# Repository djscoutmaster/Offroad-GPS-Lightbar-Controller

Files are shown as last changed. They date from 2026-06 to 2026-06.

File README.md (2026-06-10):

# Smart Light Bar Controller

GPS controller designed for **Aurora Evolve adjustable beam pattern off-road light bars**.

## Assembled GPS controlller

<p align="center">
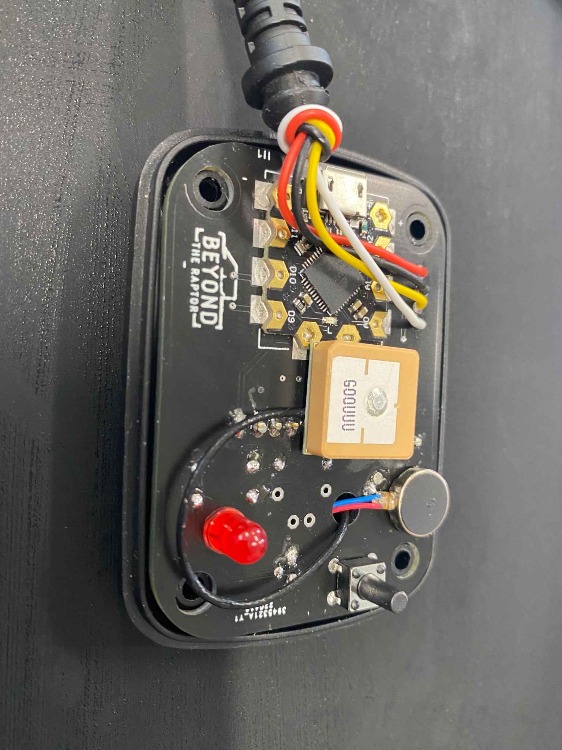
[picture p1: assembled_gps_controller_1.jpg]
Assembled GPS controller 1
  
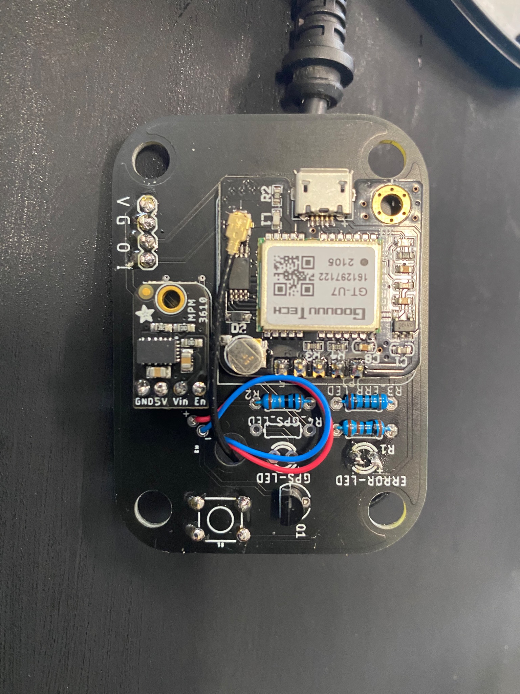
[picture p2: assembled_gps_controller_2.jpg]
Assembled GPS controller 2
  
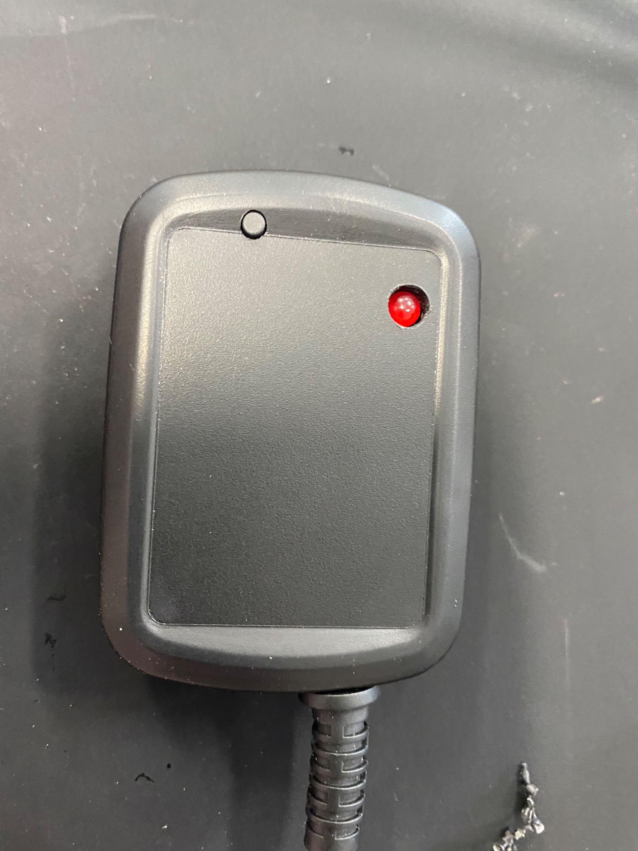
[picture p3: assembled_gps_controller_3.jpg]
Assembled GPS controller 3
  
</p>

## Aurora Evolve light bar

<p align="center">
  Aurora Evolve light bar
</p>

This project adds a smart GPS-based control layer to the Aurora Evolve system while still letting the user keep the original handheld controller behavior.

**Aurora Evolve product family:**  
https://lexbern.com/collections/aurora-evolve?srsltid=AfmBOorVTvPY1E8R5cCzJ8TLMzEkflyujZKsF8cvEtnp-r9cIhNQSOhc

**Final product demo:**  
https://www.youtube.com/watch?v=3yx3ybBsLAM

---

# Smart Light Bar Controller

Arduino-based smart controller for an off-road LED light bar. The controller sits between an existing manual lighting controller and the light bar, relays normal commands, and can automatically adjust the beam pattern based on GPS speed.

> **Project status:** Prototype / work in progress. GPS-driven light setting changes are implemented in the current sketch. Button behavior, accelerometer behavior, GPS 10 Hz updates, and non-blocking error handling are still being refined.

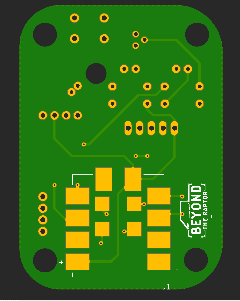
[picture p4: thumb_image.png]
Prototype board


## What it does

The Smart Light Bar Controller, or **SLC**, listens to the existing lighting controller's 5 V digital signal and retransmits compatible commands to the light bar. When GPS mode is active, the SLC uses vehicle speed to select one of six beam settings:

| Speed range example | Light setting | Beam behavior |
|---:|---:|---|
| 0-9 mph | 1 | Widest pattern |
| 10-19 mph | 2 | Wide |
| 20-29 mph | 3 | Medium-wide |
| 30-39 mph | 4 | Medium-narrow |
| 40-49 mph | 5 | Narrow |
| 50+ mph | 6 | Narrowest / spot pattern |

The default high-speed threshold is **50 mph**. The intent is for the user to be able to set that threshold from the current GPS speed using the onboard button.

## Core features

- Reads GPS speed using TinyGPS++.
- Maps speed into six light-bar settings.
- Sends the light-bar setting command over a 5 V digital output.
- Avoids resending a light setting when the setting has not changed.
- Provides six indicator LEDs for the active speed/light setting.
- Provides a status LED and an error LED.
- Includes early support for an ADXL345 accelerometer and activity/inactivity detection.
- Includes early support for a momentary button and piezo buzzer.
- Includes PCB design files, Gerbers, drill files, and assembly output.

## Hardware

See [`PARTS.md`](PARTS.md) for a cleaner parts list and recommended additions.

### Controller and modules

- Arduino-compatible controller. The requirements document calls for an **Arduino Mega 2560**. The existing parts list also references a compact **DFRobot Beetle**, so confirm which board you want as the official target before publishing.
- GPS module compatible with **NEO-6M** / **GT-U7** style serial GPS modules.
- ADXL345-compatible accelerometer.
- Piezo buzzer, such as TBM12A05-compatible.
- Momentary push button.
- Six light-setting indicator LEDs.
- One accelerometer/status LED.
- One error LED.
- 5 V digital signal interface to the existing lighting controller and light bar.

### Current Arduino pin map

| Function | Pin | Notes |
|---|---:|---|
| Button input | 2 | Uses `ezButton` debounce handling. |
| Light command transmit | 3 | Sends light-bar command timing pulses. |
| Buzzer | 4 | Uses `tone()`. Current beep functions use blocking delays. |
| GPS RX/TX constants | 19 / 18 | Defined in code, but the current sketch uses `Serial2`. Verify the final wiring. |
| Light setting LED 1 | 41 | Setting 1 / wide. |
| Light setting LED 2 | 42 | Setting 2. |
| Light setting LED 3 | 43 | Setting 3. |
| Light setting LED 4 | 44 | Setting 4. |
| Light setting LED 5 | 45 | Setting 5. |
| Light setting LED 6 | 46 | Setting 6 / spot. |
| Additional output | 47 | Configured as output; document final purpose. |
| Blue status LED | 48 | Used for GPS speed update/status in current sketch. Intended for accelerometer state. |
| Error LED | 49 | Used for GPS/error status. |

## Software dependencies

Install these libraries in the Arduino IDE Library Manager or through your preferred Arduino workflow:

- `TinyGPS++`
- `SparkFun ADXL345 Arduino Library`
- `ezButton`

## Getting started

1. Clone the repository.
2. Open `Smart_Light_Bar_Controller.ino` in the Arduino IDE.
3. Install the required libraries listed above.
4. Select the correct board. The current requirements target **Arduino Mega 2560**.
5. Confirm the GPS serial port and baud rate:
   - Default baud rate: `9600`
   - Current sketch uses `Serial2.begin(GPSBaud)`
6. Confirm all pins match your wiring.
7. Upload the sketch.
8. Open Serial Monitor at `9600` baud for debug output.

## Configuration points

The main tuning values are currently near the top of `Smart_Light_Bar_Controller.ino`:

```cpp
static const uint32_t GPSBaud = 9600;
int spotSpeed = 50;           // MPH for full spot setting
int lightSettingsSpeeds[5];   // Calculated speed thresholds
const int buzzerPin = 4;
static const int lightTXPin = 3;
```

The threshold table is recalculated by dividing `spotSpeed` into five threshold breakpoints. For example, `spotSpeed = 50` creates thresholds at 10, 20, 30, 40, and 50 mph.

## Current behavior

### GPS speed mode

When GPS speed is valid, the controller:

1. Reads the current GPS speed in mph.
2. Clears the error LED.
3. Selects the matching light setting from 1-6.
4. Turns on the matching setting LED.
5. Sends the timing pulse sequence for the selected light setting.

### Light command output

`sendLightSetting(int lightIndex)` sends the command timing pattern on `lightTXPin`. It uses the same leading pulse structure for all settings and then repeats short pulses based on the selected setting.

The function skips transmission when the requested setting is already active.

### Error behavior

The current sketch turns the error LED on while waiting for a valid GPS speed. It also halts in a `while(true)` loop if no GPS characters are processed after five seconds.

This should be changed before field use. See [`TODO.md`](TODO.md) for the recommended non-blocking error handling work.

## Planned improvements

The highest-value improvements before calling this GitHub-ready are:

- Configure the GPS module for **10 Hz updates**, or add interpolation between GPS updates.
- Replace all blocking `delay()` and `while(true)` behavior with non-blocking `millis()` state machines.
- Implement the 3-second and 10-second button hold behavior.
- Store the user-selected high-speed threshold in EEPROM.
- Finish ADXL345 interrupt handling and make inactivity/activity callbacks easy to customize.
- Flash the red error LED at 500 ms intervals when GPS speed is unavailable.
- Turn off speed-setting LEDs when not in GPS mode.
- Add bench-test instructions and a simple wiring diagram.

## Repository structure

```text
Smart_Light_Bar_Controller/
├── Smart_Light_Bar_Controller.ino      # Main Arduino sketch
├── README.md                           # Project overview and setup
├── PARTS.md                            # Cleaned-up BOM / parts list
├── TODO.md                             # Implementation checklist
├── GITHUB_PROJECT_RECOMMENDATIONS.md   # Publishing recommendations
├── thumb_image.png                     # Prototype image
└── PCB DESIGN/
    ├── *.pcbdoc / *.dxf                # PCB design exports
    └── Gerber out/
        ├── GerberFiles/                # PCB manufacturing files
        ├── DrillFiles/                 # Drill files
        └── Assembly/                   # Assembly output
```

## Safety notes

This is a vehicle electrical project. Use proper fusing, strain relief, wire gauge, waterproofing, and electrical protection before installing it in a vehicle. Do not rely on breadboard wiring for vehicle use. Validate that the controller cannot accidentally turn lights on, change modes unexpectedly, or interfere with required lighting.

## License

No license has been selected yet. Before publishing publicly, add a license file such as MIT, Apache-2.0, GPL-3.0, or a private/proprietary notice depending on how you want others to use the project.

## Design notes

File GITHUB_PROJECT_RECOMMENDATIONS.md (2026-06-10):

# GitHub Project Recommendations

These are the main improvements I would make before sharing this publicly or sending it to other builders.

## 1. Make the target hardware unambiguous

Right now the documentation points in two directions:

- The project requirements call for an Arduino Mega 2560.
- The original parts list includes a DFRobot Beetle.
- The current sketch uses pins 41-49, which only makes sense on a larger board like the Mega.

**Recommendation:** publish the first GitHub version as an **Arduino Mega 2560 prototype**. Then add a future milestone for a compact PCB/controller version.

## 2. Add one simple wiring diagram

The repo will be much easier to understand with a diagram showing:

- Existing lighting controller signal input.
- Smart Light Bar Controller board.
- Light-bar signal output.
- Shared ground.
- 12 V vehicle power into the buck converter.
- 5 V controller power.
- GPS, accelerometer, button, buzzer, and LEDs.

Even a clean hand-drawn diagram exported as PNG would help a lot.

## 3. Add a short demo video or GIF

A GitHub README for a hardware project becomes much stronger when the first screen shows it working. The best demo would show:

1. GPS speed changing.
2. Active LED setting changing from 1-6.
3. The light command being sent only when the setting changes.
4. Error LED behavior when GPS is unavailable.

## 4. Convert the code to a non-blocking state-machine style

The current sketch still uses blocking patterns like `delay()` and `while(true)`. That is risky because the controller needs to keep reading GPS, button state, accelerometer interrupts, and signal timing without freezing.

Recommended code structure:

```text
loop()
├── readGps()
├── updateGpsMode()
├── updateButtonState()
├── updateAccelerometerState()
├── updateErrorState()
├── updateIndicatorLeds()
└── transmitLightCommandIfNeeded()
```

## 5. Add a pin map diagram and constants section

The README now includes a pin table, but the code would be easier to maintain if every pin lived in one clearly labeled section:

```cpp
const uint8_t PIN_BUTTON = 2;
const uint8_t PIN_LIGHT_TX = 3;
const uint8_t PIN_BUZZER = 4;
const uint8_t PIN_LED_SETTING_1 = 41;
...
```

## 6. Add release levels

Use GitHub releases or tags like:

- `v0.1-prototype-gps-speed-control`
- `v0.2-non-blocking-button-buzzer`
- `v0.3-accelerometer-status`
- `v1.0-vehicle-tested`

This helps people understand what is tested versus experimental.

## 7. Add safety and install disclaimers

Because this interfaces with vehicle lighting and 12 V power, make it clear that builders need proper fusing, wire gauge, waterproofing, strain relief, and safe test procedures.

## 8. Decide how open you want it to be

Before publishing, choose a license:

- **MIT:** easiest for people to reuse.
- **Apache-2.0:** permissive, with stronger patent language.
- **GPL-3.0:** requires derivatives to stay open source.
- **No license / all rights reserved:** public viewing only; not really open source.

## 9. Clean up repo naming over time

For a future cleanup, consider this structure:

```text
Smart_Light_Bar_Controller/
├── firmware/
│   └── Smart_Light_Bar_Controller/
│       └── Smart_Light_Bar_Controller.ino
├── hardware/
│   ├── pcb/
│   └── gerbers/
├── docs/
│   ├── wiring.md
│   └── signal-timings.md
├── images/
├── README.md
├── PARTS.md
└── TODO.md
```

I did not restructure the repo automatically because that can break Arduino IDE expectations unless the sketch folder is moved carefully.

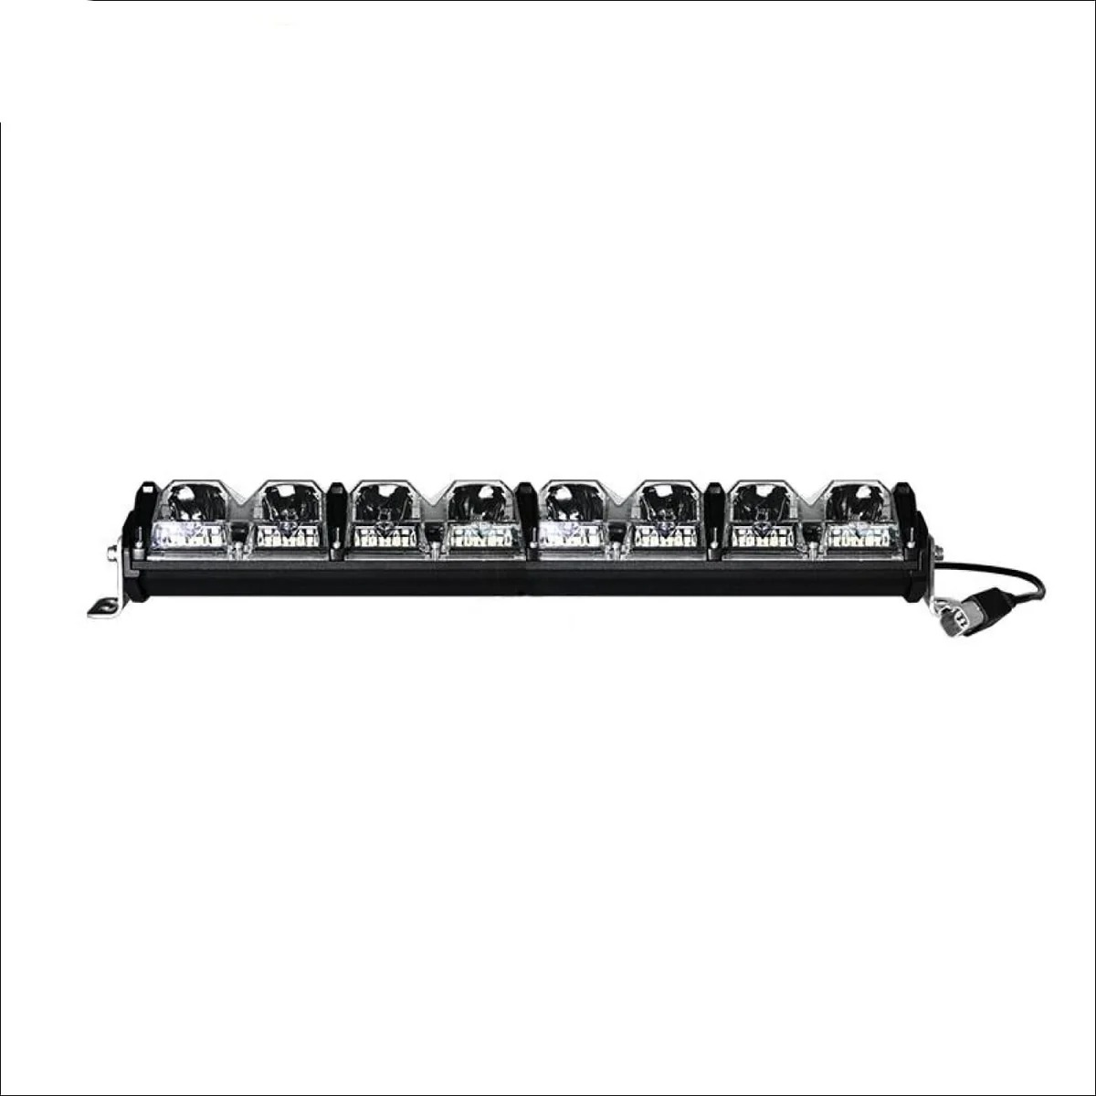
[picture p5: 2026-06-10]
docs/assets/aurora_evolve_light_bar.jpg

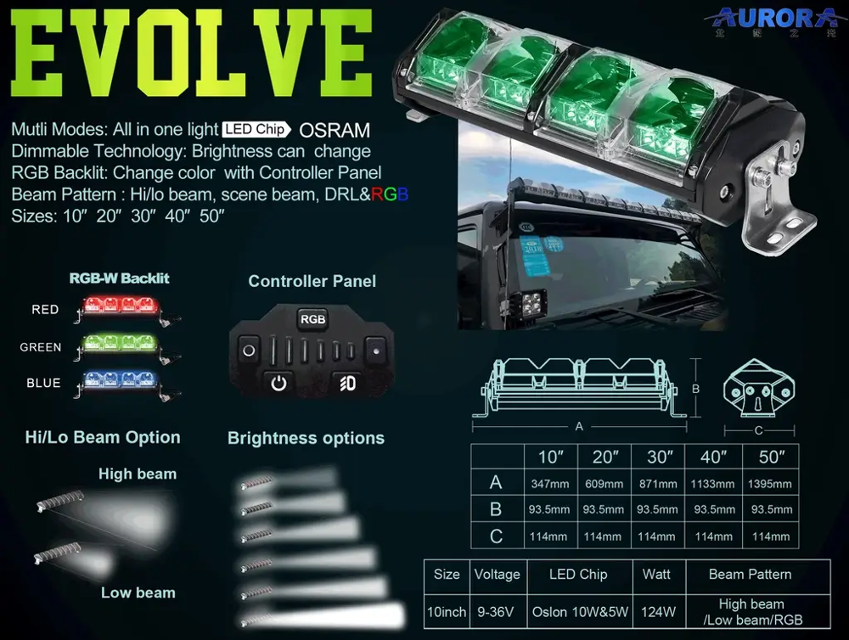
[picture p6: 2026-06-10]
aurora_evolve_light_bar_reference.png

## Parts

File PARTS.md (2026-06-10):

# Parts List / Bill of Materials

This list combines the original prototype parts list with the requirements from the project document. Items marked **Verify** need a final decision before ordering or publishing the repo.

## Required controller parts

| Qty | Part / module | Example / compatible part | Purpose | Status | Notes |
|---:|---|---|---|---|---|
| 1 | Main microcontroller | Arduino Mega 2560 | Runs the Smart Light Bar Controller sketch | **Required / verify** | The requirements target a Mega 2560. The original compact parts list references a DFRobot Beetle, so pick one official target. Current pin usage strongly favors the Mega because pins 41-49 are used. |
| 1 | GPS module | NEO-6M-compatible or GT-U7 GPS module | Reads vehicle speed | Required | Confirm serial voltage level, antenna placement, and whether the module supports 10 Hz updates. |
| 1 | Accelerometer | ADXL345-compatible module | Detects activity/inactivity state | Required / partially implemented | Use I2C or SPI consistently and document the interrupt pin. |
| 1 | Momentary push button | 6 mm x 6 mm through-hole push button | User input for speed calibration | Required | Current sketch uses pin 2 with debounce. |
| 1 | Piezo buzzer | TBM12A05-compatible | Audible feedback for button actions and status | Required | Current sketch uses pin 4. |
| 6 | Indicator LEDs | 3 mm or 5 mm LEDs | Shows active light setting 1-6 | Required | Add current-limiting resistors. |
| 1 | Blue status LED | 3 mm or 5 mm blue LED | Accelerometer/status indication | Required | Intended for inactivity/activity state. Current code also uses it during GPS update checks. |
| 1 | Red error LED | 3 mm or 5 mm red LED | GPS and signal error indication | Required | Should flash non-blocking for error states. |
| 8+ | LED resistors | 220-330 Ω typical | Limits LED current | Required | Size based on LED forward voltage and desired brightness. |
| 1 | 5 V buck regulator | Adafruit MPM3610 Buck Converter or automotive-rated 12 V-to-5 V converter | Powers controller from vehicle 12 V | Required / verify | For vehicle use, prefer an automotive-rated regulator with transient protection. |
| 1 | Enclosure | New Age Medium Utility S-352510 | Protects electronics | Prototype part | Original parts list references this enclosure. Confirm fit with final PCB and connectors. |

## Signal interface and vehicle-install parts

| Qty | Part / module | Purpose | Recommendation |
|---:|---|---|---|
| 1 | Inline fuse holder + fuse | Protects the 12 V feed | Add near the power source. Size the fuse to the controller and wiring, not the light bar. |
| 1 | Reverse-polarity protection | Protects against accidental reverse wiring | Consider a series Schottky diode or ideal-diode MOSFET circuit. |
| 1 | TVS diode or automotive transient protection | Protects against load dumps and voltage spikes | Strongly recommended for vehicle electrical systems. |
| 1 | Common ground connection | Shared reference for controller and light-bar signal | Required for reliable 5 V digital signaling. |
| As needed | Waterproof connectors | Serviceable vehicle wiring | Use locking connectors if installed in a vehicle. |
| As needed | Wire, heat-shrink, loom, strain relief | Durable install | Avoid breadboards or loose jumpers in the vehicle. |
| As needed | Headers / screw terminals | Board connections | Choose connectors that match the enclosure and vibration environment. |

## PCB and fabrication files

| File / folder | Purpose |
|---|---|
| `PCB DESIGN/PCB_PCB_Light Bar Controller v2_2_2022-02-16_2022-04-08.pcbdoc` | PCB design source/export. |
| `PCB DESIGN/PCB_PCB_Light Bar Controller v2_2_2022-02-16_2022-04-08.dxf` | Mechanical / board outline export. |
| `PCB DESIGN/Gerber out/GerberFiles/` | Gerber files for PCB fabrication. |
| `PCB DESIGN/Gerber out/DrillFiles/` | Drill files for PCB fabrication. |
| `PCB DESIGN/Gerber out/Assembly/` | Assembly output files. |

## Original compact prototype parts list

These were present in the original `Parts List.rtf` file:

| Part | Notes |
|---|---|
| DFRobot Beetle | Compact Arduino-compatible board. Verify compatibility with the current sketch before listing as the main target. |
| Adafruit MPM3610 Buck Converter | 12 V-to-5 V power conversion candidate. |
| 6 mm x 6 mm through-hole push button | User input button. |
| GT-U7 GPS module | GPS speed module. |
| Tatoko 20PCS 10 mm x 3 mm mini vibration motors, DC 3 V | Original list item. Verify if these are still needed; the requirements call for a piezo buzzer, not vibration motors. |
| New Age Medium Utility - S-352510 enclosure | Prototype enclosure. |

## Final BOM cleanup needed

Before publishing the repo publicly, I would resolve these items:

- Pick one official controller board: **Arduino Mega 2560** or **DFRobot Beetle**.
- Add exact resistor values for each LED.
- Add the exact connector types used for power, ground, controller input, and light-bar output.
- Add the final accelerometer interrupt pin.
- Add the final GPS serial port wiring and baud/update rate.
- Add links to exact purchase pages if you want the repo to be builder-friendly.
- Separate **prototype parts** from **recommended vehicle-install parts** so people do not copy breadboard-style wiring into a vehicle.

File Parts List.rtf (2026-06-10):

Controller parts list
- DFRobot Beetle
- Adafruit MPM3610 Buck Converter
- 6mmx6mm through hole push button
- gt-u7 GPS module
- tatoko 20PCS 10mmx3mm Mini Vibration Motors DC 3V
housed in a new age Medium Utility - S-352510
https://www.newageenclosures.com/enclosures/utility--desktop/medium-utility.php

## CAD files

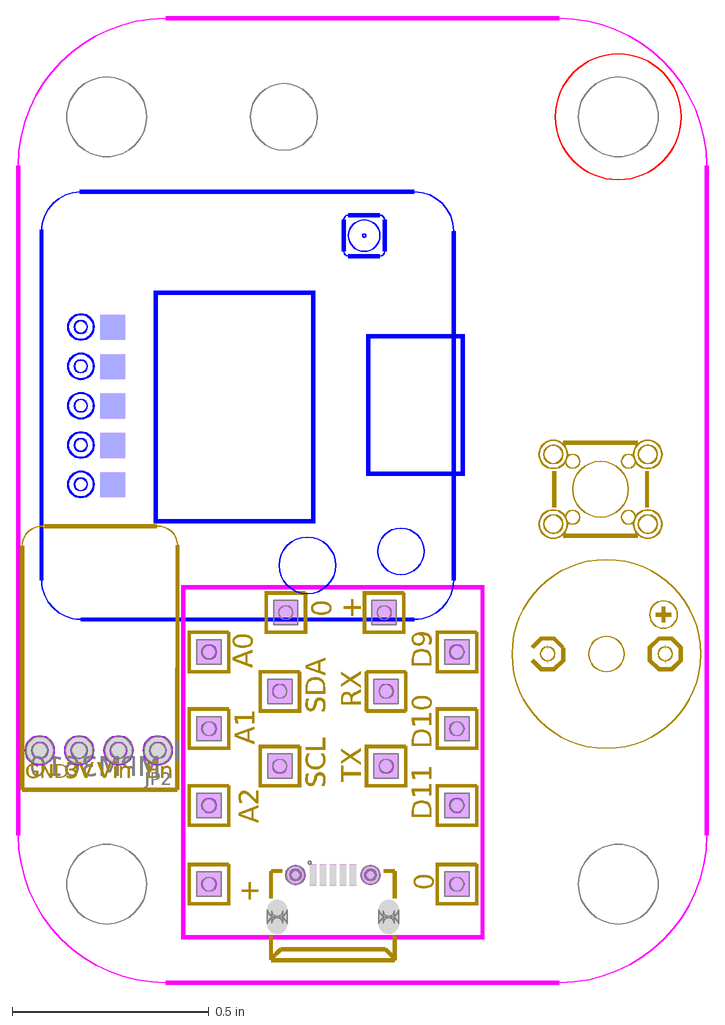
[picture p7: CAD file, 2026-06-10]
PCB DESIGN/PCB_PCB_Light Bar Controller v2_2_2022-02-16_2022-04-08.dxf
MPM3610
GND
3V
Vin
En
0
D11
D10
D9
+
RX
TX
SDA
SCL
A0
A1
A2
JP2

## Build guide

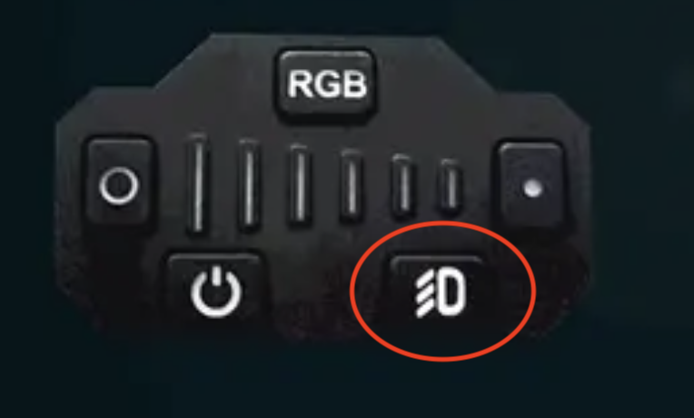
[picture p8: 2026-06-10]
docs/assets/assembled_gps_controller_3.png

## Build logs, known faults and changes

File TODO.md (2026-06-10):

# TODO / Project Roadmap

Use this as the public GitHub checklist for getting the Smart Light Bar Controller from prototype to a cleaner release.

## High priority

- [ ] Confirm the official controller board.
  - [ ] Arduino Mega 2560 if using pins 41-49.
  - [ ] Compact controller such as DFRobot Beetle only if the pin map and code are updated.
- [ ] Remove blocking behavior.
  - [ ] Replace `delay()` in buzzer functions with a non-blocking beep scheduler.
  - [ ] Replace `while(true)` GPS failure halt with a non-blocking error state.
- [ ] Finish GPS update behavior.
  - [ ] Configure GPS for 10 Hz updates if the module supports it.
  - [ ] Or add calculated/interpolated speed behavior between GPS updates.
- [ ] Implement final button behavior.
  - [ ] 3-second hold: sound 2 tones and set high-speed threshold at the 3-second mark.
  - [ ] 10-second hold: sound 4 tones and set high-speed threshold at the 10-second mark.
  - [ ] Do nothing on release after the threshold has already been handled.
  - [ ] Store threshold in EEPROM.
- [ ] Finalize low-speed behavior.
  - [ ] If default high speed is below 10 mph, use settings 1-3 only.
- [ ] Finish accelerometer behavior.
  - [ ] Turn blue LED on when inactivity is triggered.
  - [ ] Turn blue LED off when activity returns.
  - [ ] Add clearly marked callback sections for custom activity/inactivity behavior.
- [ ] Finish error LED behavior.
  - [ ] Flash red LED 500 ms on / 500 ms off when GPS speed is unavailable.
  - [ ] Flash red LED for non-matching lighting-controller signals.
- [ ] Turn off speed-setting LEDs when GPS mode is inactive.

## Documentation

- [ ] Add a wiring diagram.
- [ ] Add photos of the prototype wiring from multiple angles.
- [ ] Add a table of all lighting controller pulse timings.
- [ ] Add bench-test instructions using Serial Monitor.
- [ ] Add a short demo video or animated GIF.
- [ ] Add install notes for power, ground, fuse, enclosure, and signal wiring.

## Repo hygiene

- [ ] Add a license.
- [ ] Add a `CONTRIBUTING.md` if you want outside pull requests.
- [ ] Add GitHub issue templates for bug reports and hardware compatibility reports.
- [ ] Add a release tag once the project has one known-good working version.
- [ ] Consider moving PCB files into a cleaner `hardware/` folder in a future cleanup.

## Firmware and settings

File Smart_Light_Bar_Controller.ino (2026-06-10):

#include <TinyGPS++.h>
#include <SparkFun_ADXL345.h>         // SparkFun ADXL345 Library
#include <ezButton.h>
//#include <SoftwareSerial.h>
 
 
/*********** acellerometer COMMUNICATION SELECTION ***********/
/*    Comment Out The One You Are Not Using    */
//ADXL345 adxl = ADXL345(10);           // USE FOR SPI COMMUNICATION, ADXL345(CS_PIN);
ADXL345 adxl = ADXL345();             // USE FOR I2C COMMUNICATION
 
static const int RXPin = 19, TXPin = 18;
static const uint32_t GPSBaud = 9600;
int currentLightsetting = 0;
static const int lightTXPin = 3;
int cLight = 41;
int cSpeed = 1;
// MPH of full spot setting
int spotSpeed = 50;
int newSpeedSetting = 1;
int justbooted = 1;
unsigned long gpsSpeedMillis;
int previousGPSspeed = 0 ;
int currentGpsSpeed = 0; 
 
//Array of speeds to change light settings
int lightSettingsSpeeds[5];
int hasRecentAcitivity;
// The TinyGPS++ object
TinyGPSPlus gps;
 
//Button pressing vars
const int SHORT_PRESS_TIME = 1000; // 1000 milliseconds
const int LONG_PRESS_TIME  = 2000; // 1000 milliseconds
ezButton button(2);  // create ezButton object that attach to pin
unsigned long pressedTime  = 0;
unsigned long releasedTime = 0;
bool isPressing = false;
bool isLongDetected = false;
 
const int buzzerPin = 4; //buzzer to arduino pin 9
 
 
// The serial connection to the GPS device
//SoftwareSerial ss(RXPin, TXPin);
 
void setup()
{
 Serial.begin(9600);
 Serial2.begin(GPSBaud);
 button.setDebounceTime(50); // set debounce button time to 50 milliseconds
 
 // /*
 //     setup accelerometer
 // */
 // adxl.powerOn();                     // Power on the ADXL345
 
 // adxl.setRangeSetting(16);           // Give the range settings
 //                                     // Accepted values are 2g, 4g, 8g or 16g
 //                                     // Higher Values = Wider Measurement Range
 //                                     // Lower Values = Greater Sensitivity
 
 // adxl.setSpiBit(0);                  // Configure the device to be in 4 wire SPI mode when set to '0' or 3 wire SPI mode when set to 1
 //                                     // Default: Set to 1
 //                                     // SPI pins on the ATMega328: 11, 12 and 13 as reference in SPI Library
 
 // adxl.setActivityXYZ(1, 1, 1);       // Set to activate movement detection in the axes "adxl.setActivityXYZ(X, Y, Z);" (1 == ON, 0 == OFF)
 // adxl.setActivityThreshold(21);      // 62.5mg per increment   // Set activity   // Inactivity thresholds (0-255)
 // adxl.setInactivityXYZ(1, 1, 1);     // Set to detect inactivity in all the axes "adxl.setInactivityXYZ(X, Y, Z);" (1 == ON, 0 == OFF)
 // adxl.setInactivityThreshold(20);    // 62.5mg per increment   // Set inactivity // Inactivity thresholds (0-255)
 // adxl.setTimeInactivity(5);         // How many seconds of no activity is inactive?
 
 //  // Turn on Interrupts for each mode (1 == ON, 0 == OFF)
 // adxl.InactivityINT(1);
 // adxl.ActivityINT(1);
 
 /*
   Setup led pins
 */
 
 //Lighting control pins
  pinMode(41, OUTPUT);
  pinMode(42, OUTPUT);
  pinMode(43, OUTPUT);
  pinMode(44, OUTPUT);
  pinMode(45, OUTPUT);
  pinMode(46, OUTPUT);
  pinMode(47, OUTPUT);
 
 //Blue Ready Lighting 
  pinMode(48, OUTPUT);
 //Error led light
  pinMode(49, OUTPUT);
 // buzzer pin
  pinMode(buzzerPin, OUTPUT);

  pinMode(lightTXPin, OUTPUT);
 
 Serial.println(F("DeviceExample.ino"));
 Serial.println(F("A simple demonstration of TinyGPS++ with an attached GPS module"));
 Serial.print(F("Testing TinyGPS++ library v. ")); Serial.println(TinyGPSPlus::libraryVersion());
 Serial.println(F("by Mikal Hart"));
 Serial.println();
}
 
void loop()
{
  
 int blueLight = 0;
 //ADXL_ISR();
 // This sketch displays information every time a new sentence is correctly encoded.
 while (Serial2.available() > 0){
 
   //Check new speed and populate light settings ranges
   if(newSpeedSetting){
     Serial.println("New Speed Setting");
     int tempVar = spotSpeed / 5;
     for (byte i = 0; i < 5; i = i + 1) {
       lightSettingsSpeeds[i] = (i+1)*(tempVar);
              
       Serial.println(lightSettingsSpeeds[i]);
     }
     Serial.println("full array");
     Serial.println(lightSettingsSpeeds[0]);
     Serial.println(lightSettingsSpeeds[1]);
     Serial.println(lightSettingsSpeeds[2]);
     Serial.println(lightSettingsSpeeds[3]);
     Serial.println(lightSettingsSpeeds[4]);
     Serial.println("full done");
     //reset new speed setting
     newSpeedSetting = 0;
    
   }

    
  
   /*
   Main logic to change light bar settings based on speed     
   */ 
    if (gps.encode(Serial2.read()))
     //displayInfo();
 
    if (gps.speed.isValid())
    {
      // if(justbooted == 1){
      //   Serial.println("in just booted");
      //   previousGPSspeed = gps.speed.mph();
      //   cSpeed = previousGPSspeed;
      //   gpsSpeedMillis = millis();  //timmer for gps MPH refresh rate
      //   justbooted = 0;        
      //  }        
    
      // if(justbooted == 0 ){
      //   Serial.println("in no just booted");
      //   int currentMillis = millis();
      //   if ((currentMillis - gpsSpeedMillis) < 1000) 
      //   {
      //     int acell = (currentGpsSpeed - previousGPSspeed ) / ((currentMillis - gpsSpeedMillis)/1000);
      //     Serial.println("Acell is ---");
      //     Serial.println(acell);
      //     cSpeed = cSpeed + acell;
      //   }
      //   else{
      //     Serial.println("in 1sec else");
      //     previousGPSspeed = currentGpsSpeed;           
      //     currentGpsSpeed = gps.speed.mph();
      //     cSpeed = currentGpsSpeed;
      //     gpsSpeedMillis = millis();
      //   }

      // }
      
    
      // else {
      //   Serial.println("just booted issue") ;        
      // }

      /*
          GPS MPH speed update logging
      */      
      if(gps.speed.isUpdated()){
        int time = (millis() - gpsSpeedMillis);

        Serial.print("Speed updated to: ");
        Serial.print(gps.speed.mph());
        Serial.print(" in ");
        Serial.print(time);
        Serial.println(" milliseconds ");
        gpsSpeedMillis = millis();

        digitalWrite(48, LOW);
        

        
      }
      else if(!gps.speed.isUpdated()){
        int time = gpsSpeedMillis - millis();
        Serial.print("Speed Not Updated: ");
        Serial.println(gps.speed.mph());
        digitalWrite(48, HIGH);
      }
      else{
        Serial.println("speed update check failed");        
      }

      cSpeed = gps.speed.mph()   ;
      //Serial.println(cSpeed);
    
      // clear error light
      digitalWrite(49, LOW);
    
      if(cSpeed < lightSettingsSpeeds[0]){
    
        digitalWrite(cLight, LOW);
        digitalWrite(41, HIGH);
        cLight = 41;
        sendLightSetting(1);
        //Serial.println("1st light");
      
      }
      else if(cSpeed < lightSettingsSpeeds[1] ){
        digitalWrite(cLight, LOW);
        digitalWrite(42, HIGH);
        cLight = 42;
        sendLightSetting(2);
        //Serial.println("2th light");
      
      }
      else if(cSpeed < lightSettingsSpeeds[2] ){

        digitalWrite(cLight, LOW);
        digitalWrite(43, HIGH);
        cLight = 43;
        sendLightSetting(3);
        //Serial.println("3th light");
      
      }
      else if(cSpeed < lightSettingsSpeeds[3] ){
        digitalWrite(cLight, LOW);
        digitalWrite(44, HIGH);
        cLight = 44;
        sendLightSetting(4);
        //Serial.println("4th light");
      
      
      }
      else if(cSpeed < lightSettingsSpeeds[4]){
        digitalWrite(cLight, LOW);
        digitalWrite(45, HIGH);
        cLight = 45;
        sendLightSetting(5);
        //Serial.println("5th light");    
      }
      else if(cSpeed >= lightSettingsSpeeds[4]){
        digitalWrite(cLight, LOW);
        digitalWrite(46, HIGH);
        cLight = 46;
        sendLightSetting(6);
        //Serial.println("6th light");    
      }
      else{
        digitalWrite(49, HIGH);
        Serial.println("MPH exeption...");
        Serial.println(cSpeed);
      
      }
    }
    else
    {
      Serial.println("Waiting on gps");
      digitalWrite(49, HIGH);
    }
 
   //Inactivity check
  
   // if (ADXL_ISR()== 0){
   //   digitalWrite(48, HIGH);
 
   // }
   // else{
   //   digitalWrite(48, LOW);
 
   // }
   //button logic check
   //runButtonLogic();     
    
 }
 if (millis() > 5000 && gps.charsProcessed() < 10)
 {
   Serial.println(F("No GPS detected: check wiring."));
   while(true);
   //write login to flash red light for major error
 }
 
 
}
 
/*
 accelerometer inturrups
*/
bool ADXL_ISR() {
 int inActivity;
 // getInterruptSource clears all triggered actions after returning value
 // Do not call again until you need to recheck for triggered actions
 byte interrupts = adxl.getInterruptSource();
 
 int activity;
 // Inactivity
 if(adxl.triggered(interrupts, ADXL345_INACTIVITY)){
   Serial.println("*** INACTIVITY triggered ***");
   activity = 0;
   hasRecentAcitivity = 0;
 }
 else if(adxl.triggered(interrupts, ADXL345_ACTIVITY)){
   //Serial.println("*** ACTIVITY triggered ***");
   activity = 1;
   hasRecentAcitivity = 1;
 
    //add code here to do when activity is sensed
 }
 else if(hasRecentAcitivity){ // if recent activity has occuredbut no innactive trigger... there is still acitivity
   activity = 1;
 }
  // Activity
 
 return activity;
 }
 
void runButtonLogic(){
 button.loop(); // MUST call the loop() function first
 
 if(button.isPressed()){
   pressedTime = millis();
   isPressing = true;
   isLongDetected = false;
 }
 
 if(button.isReleased()) {
   isPressing = false;
   releasedTime = millis();
 
   long pressDuration = releasedTime - pressedTime;
 
   if( pressDuration < SHORT_PRESS_TIME ){
     Serial.println("A short press is detected");
     buzzerBeep1();
   }
 }
 
 if(isPressing == true && isLongDetected == false) {
   long pressDuration = millis() - pressedTime;
 
   if( pressDuration > LONG_PRESS_TIME ) {
     Serial.println("A long press is detected");
     isLongDetected = true;
     buzzerBeep2();     
   }
 } 
}
 
void buzzerBeep1(){
 tone(buzzerPin, 2300);
 delay(100); 
 noTone(buzzerPin);
}
void buzzerBeep2(){
 tone(buzzerPin, 2300);
 delay(100); 
 noTone(buzzerPin);
 delay(100);
 tone(buzzerPin, 2300);
 delay(100); 
 noTone(buzzerPin);
}
// GPS info debugging
void displayInfo()
{
 Serial.print(F("Location: "));
 if (gps.location.isValid())
 {
   Serial.print(gps.location.lat(), 6);
   Serial.print(F(","));
   Serial.print(gps.location.lng(), 6);
 }
 else
 {
   Serial.print(F("INVALID"));
 }
 
 Serial.print(F("  Date/Time: "));
 if (gps.date.isValid())
 {
   Serial.print(gps.date.month());
   Serial.print(F("/"));
   Serial.print(gps.date.day());
   Serial.print(F("/"));
   Serial.print(gps.date.year());
 }
 else
 {
   Serial.print(F("INVALID"));
 }
 
 Serial.print(F(" "));
 if (gps.time.isValid())
 {
   if (gps.time.hour() < 10) Serial.print(F("0"));
   Serial.print(gps.time.hour());
   Serial.print(F(":"));
   if (gps.time.minute() < 10) Serial.print(F("0"));
   Serial.print(gps.time.minute());
   Serial.print(F(":"));
   if (gps.time.second() < 10) Serial.print(F("0"));
   Serial.print(gps.time.second());
   Serial.print(F("."));
   if (gps.time.centisecond() < 10) Serial.print(F("0"));
   Serial.print(gps.time.centisecond());
 }
 else
 {
   Serial.print(F("INVALID"));
 }
 
 Serial.print(F(" ,speed="));
 if (gps.speed.isValid())
 {
   Serial.print(gps.speed.mph());
 }
 else
 {
   Serial.println("INVALID");
 }
 
 Serial.println();
}
void sendLightSetting(int lightIndex)
{

 //Serial.println("Speed Setting"+lightIndex);

  if (currentLightsetting == lightIndex ){
    Serial.println("no light change");
  }
  else {
    digitalWrite(lightTXPin, HIGH);
    delayMicroseconds(1050);
    digitalWrite(lightTXPin, LOW);
    delayMicroseconds(80);
    digitalWrite(lightTXPin, HIGH);
    delayMicroseconds(1050);
    digitalWrite(lightTXPin, LOW);
    delayMicroseconds(80);

    for (int i =0 ; i < lightIndex; i++){
      digitalWrite(lightTXPin, HIGH);
      delayMicroseconds(80);
      digitalWrite(lightTXPin, LOW);
      delayMicroseconds(80);
    }
    currentLightsetting = lightIndex;
    Serial.println("It Changed!");
  }


}
